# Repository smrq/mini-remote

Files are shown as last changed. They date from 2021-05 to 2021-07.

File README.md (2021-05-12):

# mini-remote

Tiny universal remote PCB and firmware

## PCB

The design for the PCB was done in KiCad. The PCB is designed according to the specifications of manufacturing with [JLCPCB](https://jlcpcb.com/).

### BOM

Microcontroller

* **U1** [STMicroelectronics STM8L101F3P3](https://www.mouser.com/ProductDetail/511-STM8L101F3P3)
	* STM8L101F3P6 is fine too
	* Any STM8L101FxPy is probably ok as long as the firmware can be squished to fit

LEDs

* **D1** [940nm IR LED (Everlight IR333/H0/L10)](https://www.mouser.com/ProductDetail/638-IR333-H0-L10)
* **D2** [2x3x4 LED, red (Chanzon)](https://www.amazon.com/Rectangle-Diffused-Lighting-Electronics-Components/dp/B01C3ZZT1E)
	* Or whatever LEDs you have lying around really

Resistors

* **R1** 22Ω 0805 resistor
* **R2** 2K7Ω 0805 resistor
* **R3** 1KΩ 0805 resistor
* **R4** 10KΩ 0805 resistor

Capacitors

* **C1-C2** 100nF 0805 capacitor

Transistors

* **Q1** [MMBT3906 PNP transistor](https://www.mouser.com/ProductDetail/863-MMBT3906LT3G)

Etc.

* **SW1-SW22** 20x [E-Switch LL3301NF065QG](https://www.mouser.com/ProductDetail/612-LL3301NF065QG)
	* Note that SW2 and SW9 are omitted from this design
* **BT1** [Linx Technologies BAT-HLD-001 CR2032 battery holder](https://www.mouser.com/ProductDetail/712-BAT-HLD-001)
* **J1** 4-pin 2.54mm header (for programming the microcontroller)
* **J2** 2-pin 2.54mm header (optional, for debugging only)

## Firmware

Building the firmware is done with Docker, but flashing the firmware requires USB hardware access that is beyond my Docker capabilities, if it is possible at all.

Prerequisites:

* Install Docker
* Install [stm8flash](https://github.com/vdudouyt/stm8flash) and make sure it is in your PATH
* Run `make docker` to build the Docker image

Building and flashing:

* `make` to build the firmware hex file
* `make flash` to flash the firmware

I used [this cheap knockoff ST-Link V2 programmer (HiLetgo V2)](https://www.amazon.com/HiLetgo-Emulator-Downloader-Programmer-STM32F103C8T6/dp/B07SQV6VLZ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) with no problems.

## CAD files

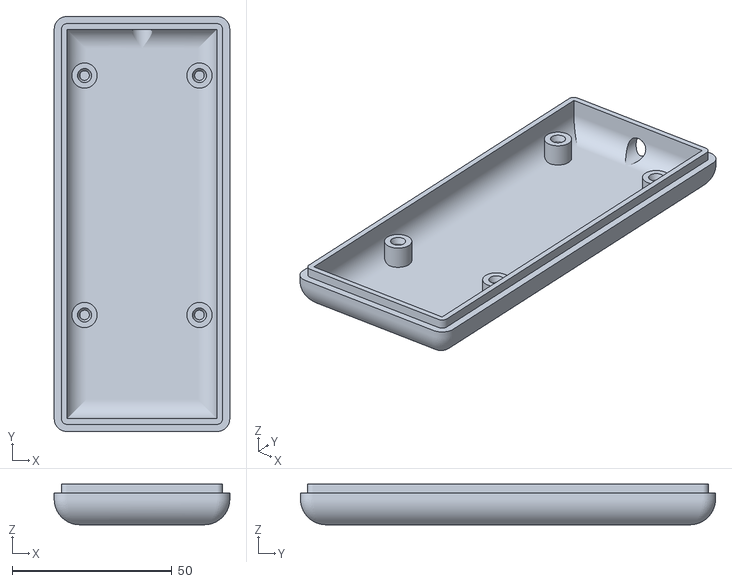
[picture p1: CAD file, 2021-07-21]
model/stl/bottom-v1-5.stl
55.0 x 130.0 x 12.7

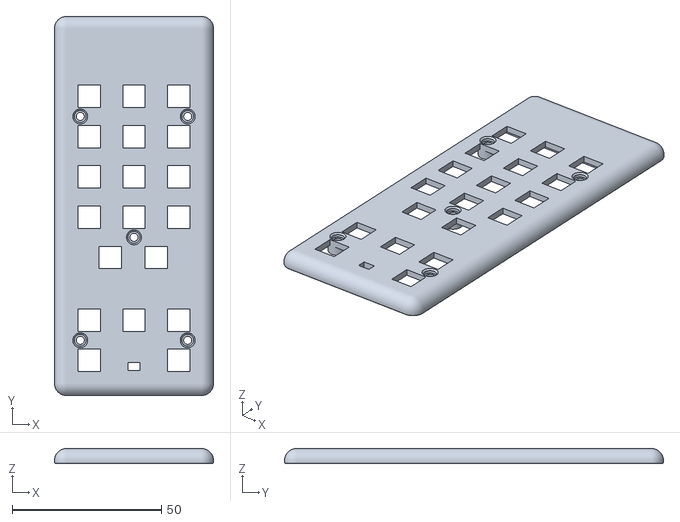
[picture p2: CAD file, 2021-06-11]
model/stl/top-v1-3.stl
53.3 x 127.0 x 5.00

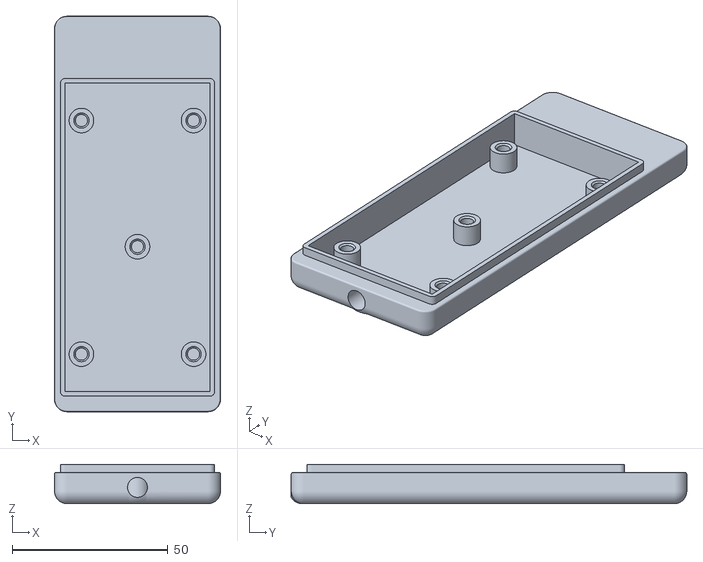
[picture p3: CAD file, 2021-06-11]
model/stl/bottom-v1-3.stl
53.3 x 127.0 x 12.6

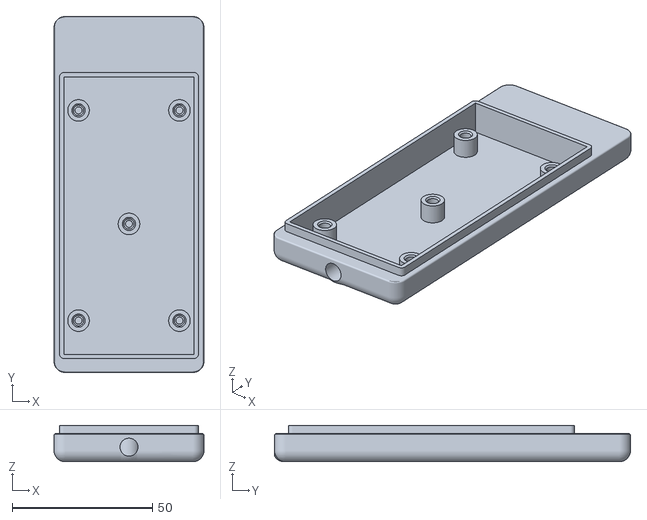
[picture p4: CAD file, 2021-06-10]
model/stl/bottom-v1-2.stl
53.5 x 127.0 x 13.0

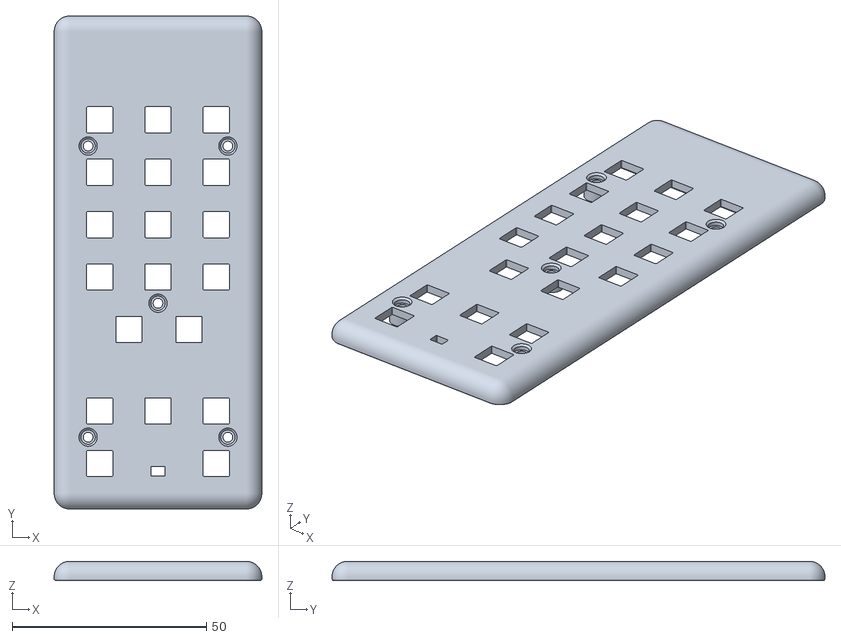
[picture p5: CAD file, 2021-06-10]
model/stl/top-v1-2.stl
53.5 x 127.0 x 5.00

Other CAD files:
model/stl/bottom-v1-1.stl
model/stl/top-v1-1.stl

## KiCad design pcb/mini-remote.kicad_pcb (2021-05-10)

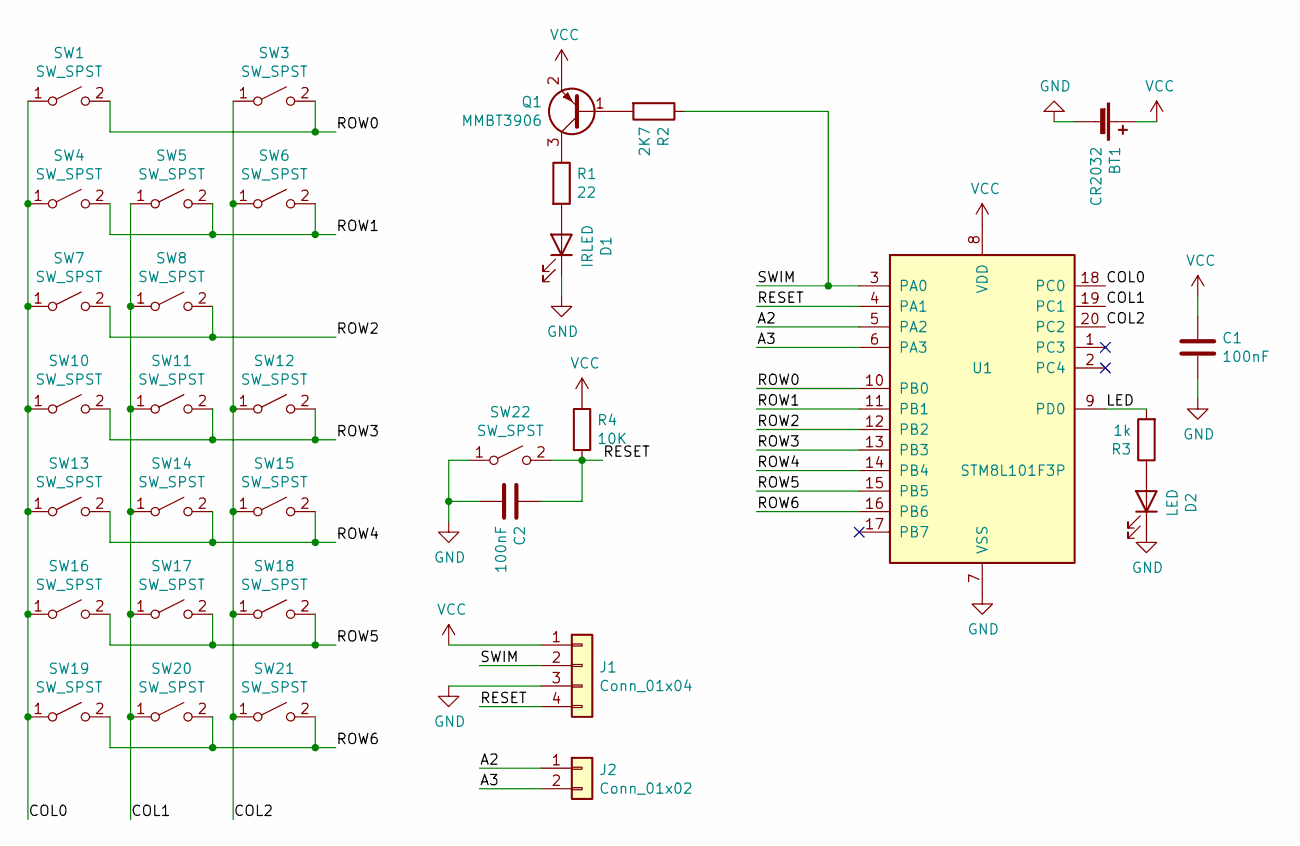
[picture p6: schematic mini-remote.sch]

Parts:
BT1: CR2032; BATHLD001
C1, C2: 100nF; C_0805_2012Metric
D1: IRLED; LED_D5.0mm
D2: LED; LED_Rectangular_W3.0mm_H2.0mm
J1: Conn_01x04; PinHeader_1x04_P2.54mm_Vertical
J2: Conn_01x02; PinHeader_1x02_P2.54mm_Vertical
Q1: MMBT3906; SOT-23
R1: 22; R_0805_2012Metric
R2: 2K7; R_0805_2012Metric
R3: 1k; R_0805_2012Metric
R4: 10K; R_0805_2012Metric
SW1, SW3, SW4, SW5, SW6, SW7, SW8, SW10, SW11, SW12, SW13, SW14, SW15, SW16, SW17, SW18, SW19, SW20, SW21, SW22: SW_SPST; LL3301NF065QG
U1: STM8L101F3P; TSSOP-20_4.4x6.5mm_P0.65mm

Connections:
/A2: J2.1, U1.5 (PA2)
/A3: J2.2, U1.6 (PA3)
/COL0: SW1.1 (A), SW4.1 (A), SW7.1 (A), SW10.1 (A), SW13.1 (A), SW16.1 (A), SW19.1 (A), U1.18 (PC0)
/COL1: SW5.1 (A), SW8.1 (A), SW11.1 (A), SW14.1 (A), SW17.1 (A), SW20.1 (A), U1.19 (PC1)
/COL2: SW3.1 (A), SW6.1 (A), SW12.1 (A), SW15.1 (A), SW18.1 (A), SW21.1 (A), U1.20 (PC2)
/LED: R3.2, U1.9 (PD0)
/RESET: C2.1, J1.4, R4.2, SW22.2 (B), U1.4 (PA1)
/ROW0: SW1.2 (B), SW3.2 (B), U1.10 (PB0)
/ROW1: SW4.2 (B), SW5.2 (B), SW6.2 (B), U1.11 (PB1)
/ROW2: SW7.2 (B), SW8.2 (B), U1.12 (PB2)
/ROW3: SW10.2 (B), SW11.2 (B), SW12.2 (B), U1.13 (PB3)
/ROW4: SW13.2 (B), SW14.2 (B), SW15.2 (B), U1.14 (PB4)
/ROW5: SW16.2 (B), SW17.2 (B), SW18.2 (B), U1.15 (PB5)
/ROW6: SW19.2 (B), SW20.2 (B), SW21.2 (B), U1.16 (PB6)
/SWIM: J1.2, R2.1, U1.3 (PA0)
GND: BT1.2 (-), C1.2, C2.2, D1.1 (K), D2.1 (K), J1.3, SW22.1 (A), U1.7 (VSS)
unnamed: D1.2 (A), R1.2
unnamed: D2.2 (A), R3.1
unnamed: Q1.1 (B), R2.2
unnamed: Q1.3 (C), R1.1
VCC: BT1.1 (+), C1.1, J1.1, Q1.2 (E), R4.1, U1.8 (VDD)

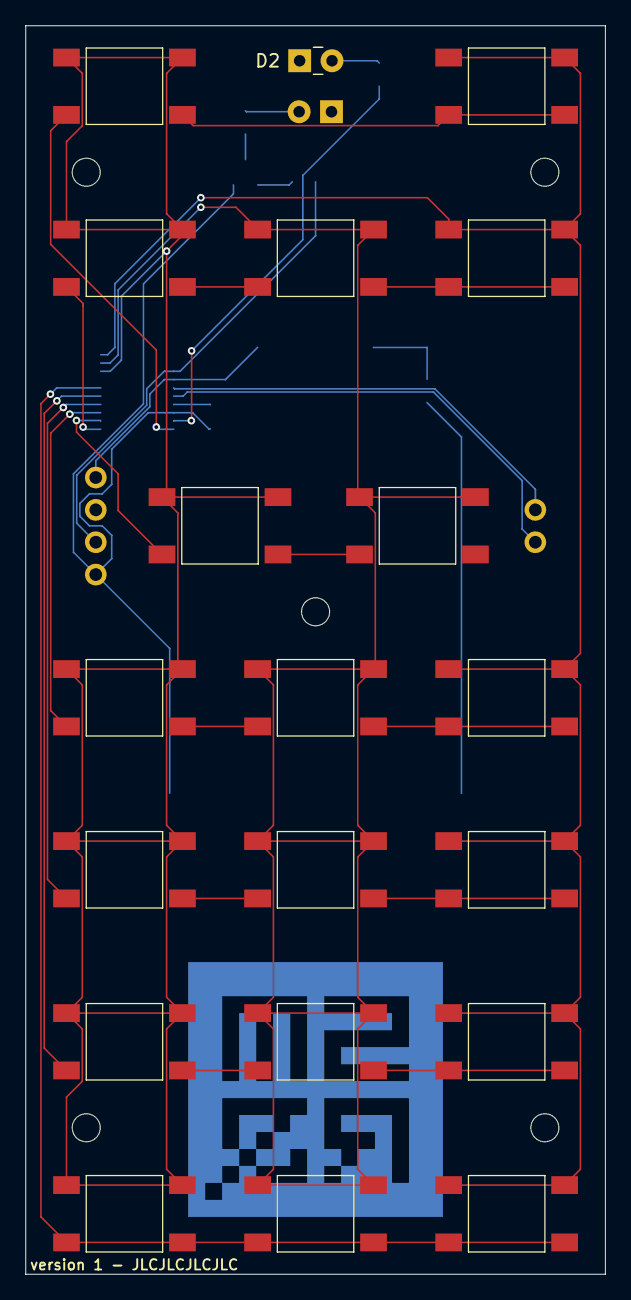
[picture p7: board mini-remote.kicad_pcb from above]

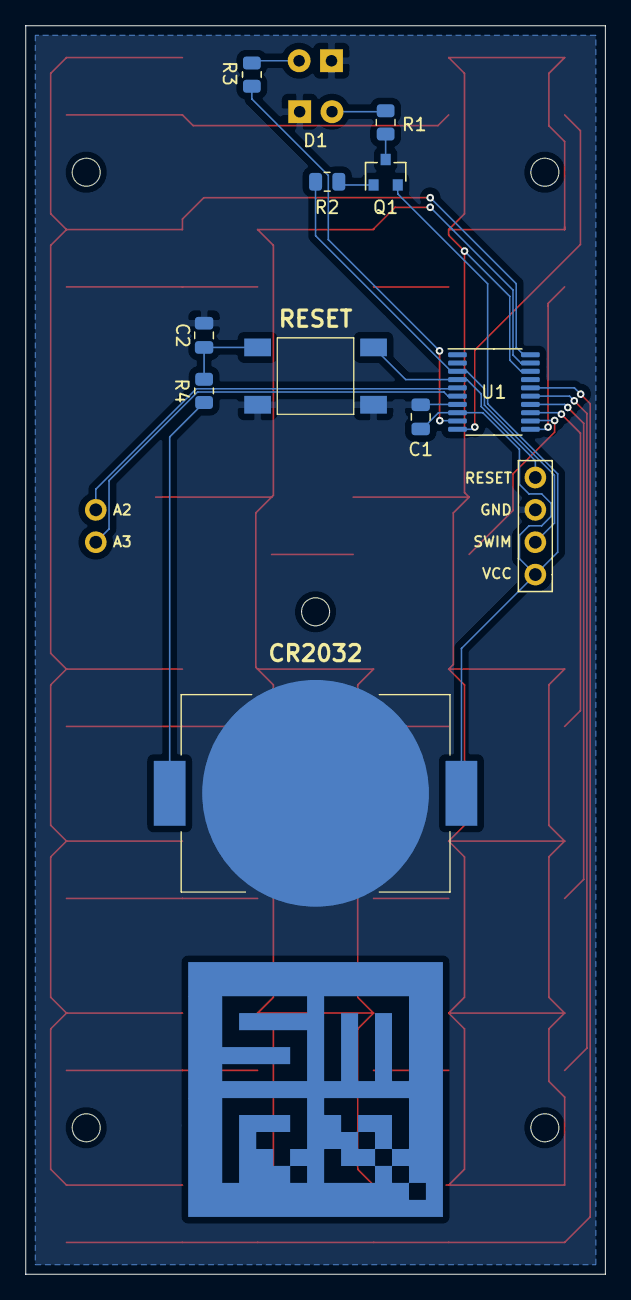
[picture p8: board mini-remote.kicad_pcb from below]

Board: 2 copper layers, 45.5 x 98.0 mm, 33 parts (13 on the bottom side), 21 nets.

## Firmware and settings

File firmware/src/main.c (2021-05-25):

#include "main.h"

MessageFormat message_format;
u8 address;
u8 command;

SendState send_state;
u8 send_bit;
u8 send_burst;

u32 messages[COL_COUNT * ROW_COUNT] = {
	MESSAGE_16(0x0702),         // 0,0: TV power (Samsung format)
	NO_MESSAGE(),               // 0,1: No button
	MESSAGE_16(0xA50A),         // 0,2: Volume up
	MESSAGE_16(0xA51C),         // 1,0: Receiver power
	MESSAGE_16(0xA512),         // 1,1: Mute
	MESSAGE_16(0xA50B),         // 1,2: Volume down
	MESSAGE_32(0xA556, 0xA5C1), // 2,0: Previous input
	MESSAGE_16(0xA555),         // 2,1: Next input
	NO_MESSAGE(),               // 2,2: No button
	MESSAGE_32(0xA55E, 0xA5CA), // 3,0: HDMI 1
	MESSAGE_32(0xA55E, 0xA5CB), // 3,1: HDMI 2
	MESSAGE_32(0xA55E, 0xA5CC), // 3,2: HDMI 3
	MESSAGE_32(0xA55E, 0xA5C7), // 4,0: HDMI 5
	MESSAGE_16(0xA50C),         // 4,1: TV
	MESSAGE_16(0xA516),         // 4,2: Video 1
	NO_MESSAGE(),               // 5,0: Not assigned
	NO_MESSAGE(),               // 5,1: Not assigned
	NO_MESSAGE(),               // 5,2: Not assigned
	NO_MESSAGE(),               // 6,0: Not assigned
	NO_MESSAGE(),               // 6,1: Not assigned
	NO_MESSAGE(),               // 6,2: Not assigned
};

u8 messageFormats[COL_COUNT * ROW_COUNT] = {
	FORMAT_SAMSUNG, FORMAT_NEC, FORMAT_NEC, // Row 0
	FORMAT_NEC, FORMAT_NEC, FORMAT_NEC, // Row 1
	FORMAT_NEC, FORMAT_NEC, FORMAT_NEC, // Row 2
	FORMAT_NEC, FORMAT_NEC, FORMAT_NEC, // Row 3
	FORMAT_NEC, FORMAT_NEC, FORMAT_NEC, // Row 4
	FORMAT_NEC, FORMAT_NEC, FORMAT_NEC, // Row 5
	FORMAT_NEC, FORMAT_NEC, FORMAT_NEC, // Row 6
};

void main(void) {
	init();

	led_on();
	_delay_ms(250);
	led_off();
	_delay_ms(250);
	led_on();
	_delay_ms(250);
	led_off();

	for(;;) {
		// Wait for EXTIB to wake processor
		enable_extib();
		_halt();
		disable_extib();

		led_on();

		u8 button;
		while ((button = read_button_matrix()) != 0xFF) {
			message_format = get_message_format(button);
			u32 message = get_message(button);

			while (message != 0) {
				command = message & 0xFF;
				address = (message >> 8) & 0xFF;
				message = message >> 16;
				send_state = SEND_HEADER1;
				send_burst = 0;

				run_tx_state_machine();
				enable_ir();

				// TODO: use wake timer to delay until 108ms from start of tx
				while (send_state != SEND_IDLE) {}
				_delay_ms(40);
			}
		}

		led_off();
	}
}

void isr_extib(void) __interrupt(INT_EXTIB) {
	debug_2_toggle();
	clear_extib();
}

void isr_tim3_update(void) __interrupt(INT_TIM3_UPDATE) {
	run_tx_state_machine();
	clear_tim3_update();
}

ButtonId read_button_matrix(void) {
	// Columns are normally low (open drain) in order to trigger interrupts on any button press.
	// To determine which button is held, bring all columns high and then check each column one
	// by one.
	ButtonId result = 0xFF;

	PC_ODR |= COL_MASK;

	for (u8 col = 0; col < COL_COUNT; ++col) {
		PC_ODR &= ~(1 << col);
		for (u8 row = 0; row < ROW_COUNT; ++row) {
			if (!(PB_IDR & (1 << row))) {
				result = COL_COUNT*row + col;
				goto break_outer;
			}
		}
		PC_ODR |= (1 << col);
	}
	break_outer:

	PC_ODR &= ~COL_MASK;
	return result;
}

u32 get_message(u8 button) {
	return messages[button];
}

MessageFormat get_message_format(u8 button) {
	return messageFormats[button];
}

void run_tx_state_machine(void) {
	switch (send_state) {
		case SEND_HEADER1:
			set_tim3_high();
			if (++send_burst == (message_format == FORMAT_SAMSUNG ? 8 : 16)) {
				send_state = SEND_HEADER2;
				send_burst = 0;
			}
			break;

		case SEND_HEADER2:
			set_tim3_low();
			if (++send_burst == 8) {
				send_state = SEND_ADDRESS1;
				send_bit = 0;
				send_burst = 0;
			}
			break;

		case SEND_ADDRESS1:
			if (send_burst == 0) {
				set_tim3_high();
			} else {
				set_tim3_low();
			}

			if (address & (1 << send_bit)) {
				if (++send_burst == 4) {
					send_burst = 0;
					++send_bit;
				}
			} else {
				if (++send_burst == 2) {
					send_burst = 0;
					++send_bit;
				}
			}

			if (send_bit == 8) {
				send_state = SEND_ADDRESS2;
				send_bit = 0;
			}

			break;

		case SEND_ADDRESS2:
			if (send_burst == 0) {
				set_tim3_high();
			} else {
				set_tim3_low();
			}

			if ((message_format == FORMAT_SAMSUNG ? address : ~address) & (1 << send_bit)) {
				if (++send_burst == 4) {
					send_burst = 0;
					++send_bit;
				}
			} else {
				if (++send_burst == 2) {
					send_burst = 0;
					++send_bit;
				}
			}

			if (send_bit == 8) {
				send_state = SEND_COMMAND1;
				send_bit = 0;
			}
			
			break;

		case SEND_COMMAND1:
			if (send_burst == 0) {
				set_tim3_high();
			} else {
				set_tim3_low();
			}

			if (command & (1 << send_bit)) {
				if (++send_burst == 4) {
					send_burst = 0;
					++send_bit;
				}
			} else {
				if (++send_burst == 2) {
					send_burst = 0;
					++send_bit;
				}
			}

			if (send_bit == 8) {
				send_state = SEND_COMMAND2;
				send_bit = 0;
			}

			break;

		case SEND_COMMAND2:
			if (send_burst == 0) {
				set_tim3_high();
			} else {
				set_tim3_low();
			}

			if (~command & (1 << send_bit)) {
				if (++send_burst == 4) {
					send_burst = 0;
					++send_bit;
				}
			} else {
				if (++send_burst == 2) {
					send_burst = 0;
					++send_bit;
				}
			}

			if (send_bit == 8) {
				send_state = SEND_FOOTER;
				send_bit = 0;
			}
			
			break;

		case SEND_FOOTER:
			set_tim3_high();
			send_state = SEND_DONE;
			break;

		case SEND_DONE:
			set_tim3_low();
			disable_ir();
			send_state = SEND_IDLE;
			break;

		case SEND_IDLE:
			break;
	}
}

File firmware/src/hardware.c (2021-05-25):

#include "hardware.h"

void led_on(void) {
	PD_ODR |= 0x01;
}

void led_off(void) {	
	PD_ODR &= ~0x01;
}

void debug_1_on(void){
	PA_ODR |= 0x04;
}

void debug_1_off(void){
	PA_ODR &= ~0x04;
}

void debug_1_toggle(void){
	PA_ODR ^= 0x04;
}

void debug_2_on(void){
	PA_ODR |= 0x08;
}

void debug_2_off(void){
	PA_ODR &= ~0x08;
}

void debug_2_toggle(void){
	PA_ODR ^= 0x08;
}

void enable_extib(void) {
	PB_CR2 |= 0x7F;
}

void disable_extib(void) {
	PB_CR2 &= ~0x7F;
}

void clear_extib(void) {
	EXTI_SR2 |= 0x01;
}

void clear_tim3_update(void) {
	TIM3_SR1 &= ~0x01;
}

void set_tim3_low(void) {
	TIM3_CCMR1 &= ~(0b111 << 4);
	TIM3_CCMR1 |= 0b100 << 4;
}

void set_tim3_high(void) {
	TIM3_CCMR1 &= ~(0b111 << 4);
	TIM3_CCMR1 |= 0b101 << 4;
}

void enable_ir(void) {
	TIM2_CNTRH = 0;
	TIM2_CNTRL = 0;
	TIM2_CR1 |= 0x01; // Enable timer
	TIM2_BKR |= 0xF0; // Enable timer CC1 output

	TIM3_CNTRH = 0;
	TIM3_CNTRL = 0;
	TIM3_CR1 |= 0x01; // Enable timer	
	TIM3_BKR |= 0xF0; // Enable timer CC1 output

	// 0: Enable IR output
	// 1: Enable high sink LED driver
	IR_CR = 0b00000001;
	// IR_CR = 0b00000011;
}

void disable_ir(void) {
	IR_CR = 0x00;

	TIM2_BKR &= ~0xF0; // Disable timer CC1 output
	TIM2_CR1 &= ~0x01; // Disable timer

	TIM3_BKR &= ~0xF0; // Disable timer CC1 output
	TIM3_CR1 &= ~0x01; // Disable timer	
}

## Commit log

2021-05-06 Initial PCB design
    [mini-remote.kicad_pcb, mini-remote.sch]
2021-05-08 Fix pcb error
    [mini-remote.kicad_pcb, mini-remote.sch]
2021-05-08 Some pin assignments
2021-05-08 Blink from button input
2021-05-10 Working single button remote
2021-05-10 PCB version 1
    [mini-remote-B_Mask.gbr, mini-remote-B_SilkS.gbr, mini-remote-Back.gbr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]
2021-05-12 Fix wrong footprint in schematic
    [mini-remote.sch]
2021-05-25 Program all the buttons
2021-05-25 Fix issue with Samsung
    [main.c]
2021-05-25 Update button layout
2021-05-31 Move pcb files
    [mini-remote-B_Mask.gbr, mini-remote-B_SilkS.gbr, mini-remote-Back.gbr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]
2021-06-01 Case model
2021-06-10 Adjust case model tolerances
2021-06-10 Case model v1.1
    [bottom-v1-1.stl, top-v1-1.stl]
2021-06-10 Case model v1.2
    [bottom-v1-2.stl, model.FCStd, top-v1-2.stl]
2021-06-11 Case model v1.3
    [bottom-v1-3.stl, model.FCStd, top-v1-3.stl]
2021-07-21 Case model v1.4
    [model.FCStd]
2021-07-21 Case model v1.5
    [bottom-v1-5.stl]
